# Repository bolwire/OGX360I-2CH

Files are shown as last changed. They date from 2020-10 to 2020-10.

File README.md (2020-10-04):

This project builds on the original OGX360 by Ryzee119: https://github.com/Ryzee119/ogx360/

The information provided in this repo is for informational purposes only at this time.

*****IMPORTANT******
The most recent prototype USB PCB required changes to be made, I have updated the schematic and PCB layout, and tested by modifying
the PCB I have on hand, however caution should be used until the new prototype is verified. Once I have verified the changes I will remove this
notice.

The ATMEGA32U4 chips will need to be programmed with the arduino bootloader before they are put on the PCB. One option may be to remove the chips
from an arduino and transplant them. I accomplish this currently by using a jig that I will release the files for at a later time.

More will be added to this repo as I find time over the next week.

Please respect the license files found within this project. What we do, and the joy we gain from that would not be possible without those who shared the
information with us to start with. Please respect and honor that by doing the same with any works derived from this or other projects linked to in this repo.

Also my spelling sucks, so I apologize for any type-ohs that exist.

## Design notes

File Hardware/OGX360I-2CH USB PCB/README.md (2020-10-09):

# OGX360I-2CH USB PCB.
This board was designed using [Autodesk Eagle](https://www.autodesk.com/products/eagle/overview). You can edit the `.brd` and `.sch` with this program.

## Printed Circuit Board
When fabricating your own, you can download the premade gerbers or generate your own. Suggested PCB properties are:  <br>
*2 layers, 19x42mm, 1.6mm thick, HASL, 1oz copper, no castellated holes, any colour you want!*<br>

## Bill of Materials
All the passive components listed (Resistors, capacitors etc) are listed for reference only. Any equivalents you find would be suitable. Use your best judgement. 
You should check this list against the schematic to ensure nothing is missed.  
**Digikey Quick Cart: http://www.digikey.com/short/zw017j**  

| Qty | Value/Model | Description | Marking | URL (Passive components provided as sample only) |
| --- | --- | --- | --- | --- |
| 1 | RC0805JR-0791RL | RES SMD 91 OHM 5% 1/8W 0805 | R1 | https://www.digikey.com/product-detail/en/yageo/RC0805JR-0791RL/311-91ARCT-ND/731331 |
| 1 | AU-Y1006 | CONN RCPT USB1.1 TYPEA 4P SMD RA | USB | https://www.digikey.com/product-detail/en/assmann-wsw-components/AU-Y1006/AE11182-ND/278927 |
| 1 | PCM12SMTR | SWITCH SLIDE SPDT 300MA 6V | SW1 | https://www.digikey.com/product-detail/en/c-k/PCM12SMTR/401-2016-1-ND/1640125 |
| 1 | SM06B-SRSS-TB(LF)(SN) | CONN HEADER SMD R/A 6POS 1MM | CONN / J1 | https://www.digikey.com/product-detail/en/jst-sales-america-inc/SM06B-SRSS-TB-LF-SN/455-1806-1-ND/926877 |
| 1 | A06SR06SR30K254A | JUMPER 06SR-3S - 06SR-3S 10" | CABLE | https://www.digikey.com/product-detail/en/jst-sales-america-inc/A06SR06SR30K254A/455-3647-ND/9922197 |
| 1 | 150080GS75000 | LED GREEN CLEAR 0805 SMD | LED | https://www.digikey.com/product-detail/en/w-rth-elektronik/150080GS75000/732-4983-1-ND/4489913 |

## Assembled Photo (coming soon)
Top Side Photo
Bottom Side Photo
By KingLuxor

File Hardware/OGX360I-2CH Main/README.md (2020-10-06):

# OGX360I-2CH Main PCB.
This board was designed using [Autodesk Eagle](https://www.autodesk.com/products/eagle/overview). You can edit the `.brd` and `.sch` with this program.

## Printed Circuit Board
When fabricating your own, you can download the premade gerbers or generate your own. Suggested PCB properties are:  <br>
*2 layers, 35x71mm, 1.6mm thick, HASL, 1oz copper, no castellated holes, any colour you want!*<br>

## Bill of Materials
All the passive components listed (Resistors, capacitors etc) are listed for reference only. Any equivalents you find would be suitable. Use your best judgement. 
You should check this list against the schematic to ensure nothing is missed.  
**Digikey Quick Cart: http://www.digikey.com/short/zwrw47**  

| Qty | Value/Model | Description | Marking | URL (Passive components provided as sample only) |
| --- | --- | --- | --- | --- |
| 2 | B12B-PHDSS(LF)(SN) | CONN HEADER VERT 12POS 2MM | J4,J5 | https://www.digikey.com/product-detail/en/jst-sales-america-inc/B12B-PHDSS-LF-SN/455-1763-ND/926669 |
| 1 | ‎B6B-PH-K-S(LF)(SN) | CONN HEADER VERT 6POS 2MM | J6 | https://www.digikey.com/product-detail/en/jst-sales-america-inc/B6B-PH-K-S-LF-SN/455-1708-ND/926615 |
| 1 | MIC5219-3.3YM5-TR | IC REG LINEAR 3.3V 500MA SOT23-5‎ | U3 | https://www.digikey.com/product-detail/en/microchip-technology/MIC5219-3.3YM5-TR/576-1281-1-ND/771902 |
| 9 | 08056D104KAT2A | CAP CER 0.1UF 6.3V X5R 0805 | C1,4-5,7-8,10-11,15-16 | https://www.digikey.com/product-detail/en/avx-corporation/08056D104KAT2A/478-08056D104KAT2ACT-ND/11569296 |
| 2 | CC0805JRNPO9BN180 | CAP CER 18PF 50V C0G/NPO 0805 | C2-3 | https://www.digikey.com/product-detail/en/yageo/CC0805JRNPO9BN180/311-1102-1-ND/303012 |
| 1 | EDK106M035A9BAA | CAP ALUM 10UF 20% 35V SMD | C6 | https://www.digikey.com/product-detail/en/kemet/EDK106M035A9BAA/399-14794-1-ND/7319832 |
| 2 | C0805C105Z4VACTU | CAP CER 1UF 16V Y5V 0805 | C9, C14 | https://www.digikey.com/product-detail/en/kemet/C0805C105Z4VACTU/399-8011-1-ND/3471734 |
| 4 | C0805C220J5GACTU | CAP CER 22PF 50V C0G/NP0 0805 | C12-13,17-18 | https://www.digikey.com/product-detail/en/kemet/C0805C220J5GACTU/399-1113-1-ND/411388 |
| 2 | 10118192-0001LF | CONN RCPT USB2.0 MICRO B SMD R/A | J2-3 | https://www.digikey.com/product-detail/en/amphenol-icc-fci/10118192-0001LF/609-4613-1-ND/2785378 |
| 2 | RC0805FR-0733RL | RES SMD 33 OHM 1% 1/8W 0805 | R1-2 | https://www.digikey.com/product-detail/en/yageo/RC0805FR-0733RL/311-33.0CRCT-ND/730809 |
| 2 | RC0805FR-072KL | RES SMD 2K OHM 1% 1/8W 0805 | R3-4 | https://www.digikey.com/product-detail/en/yageo/RC0805FR-072KL/311-2.00KCRCT-ND/730611 |
| 1 | RC0805JR-071KL | RES SMD 1K OHM 5% 1/8W 0805 | R5 | https://www.digikey.com/product-detail/en/yageo/RC0805JR-071KL/311-1.0KARCT-ND/731165 |
| 4 | RC0805JR-0722RL | RES SMD 22 OHM 5% 1/8W 0805 | R6-7,9-10 | https://www.digikey.com/product-detail/en/yageo/RC0805JR-0722RL/311-22ARCT-ND/731232 |
| 2 | RC0805FR-0710KL | RES SMD 10K OHM 1% 1/8W 0805 | R8,R11 | https://www.digikey.com/product-detail/en/yageo/RC0805FR-0710KL/311-10.0KCRCT-ND/730482 |
| 1 | TL3305AF160QG | SWITCH TACTILE SPST-NO 50MA 12V | RESET | https://www.digikey.com/product-detail/en/e-switch/TL3305AF160QG/EG5350CT-ND/5816195 |
| 1 | MAX3421EEHJ+T | IC USB PERIPH/HOST CNTRL 32TQFP | U1 | https://www.digikey.com/product-detail/en/maxim-integrated/MAX3421EEHJ-T/MAX3421EEHJ-TCT-ND/4895460 |
| 1 | CD74HC4050M96 | IC BUFFER NON-INVERT 6V 16SOIC | U2 | https://www.digikey.com/product-detail/en/texas-instruments/CD74HC4050M96/296-14529-1-ND/555596 |
| 2 | ATMEGA32U4-AUR | IC MCU 8BIT 32KB FLASH 44TQFP | U4-5 | https://www.digikey.com/product-detail/en/microchip-technology/ATMEGA32U4-AUR/ATMEGA32U4-AURCT-ND/3440960 |
| 2 | TSX-3225 16.0000MF09Z-AC0 | CRYSTAL 16.0000MHZ 9PF SMD | X2-3 | https://www.digikey.com/product-detail/en/epson/TSX-3225-16.0000MF09Z-AC0/SER4069CT-ND/5413938 |
| 1 | FA-238V 12.0000MB-W3 | CRYSTAL 12.0000MHZ 12PF SMD | X1 | https://www.digikey.com/product-detail/en/epson/FA-238V-12.0000MB-W3/SER3683CT-ND/2403456 |
| 2 | PHDR-12VS | CONN HOUSING PHD 12POS 2MM DUAL | --- | https://www.digikey.com/product-detail/en/jst-sales-america-inc/PHDR-12VS/455-1204-ND/608645 |
| 10 | APAPA22K152 | JUMPER SPHD-001T-P0.5 X2 6" | --- | https://www.digikey.com/product-detail/en/jst-sales-america-inc/APAPA22K152/455-3085-ND/6009461 |
| 1 | 0ZCJ0050FF2G | PTC RESET FUSE 8V 500MA 1206 | F1 | https://www.digikey.com/product-detail/en/bel-fuse-inc/0ZCJ0050FF2G/507-1802-1-ND/4156236 |
| 2 | TMUX1237DCKR | PRECISION ANALOG MULTIPLEXER | U6-7 | https://www.digikey.com/product-detail/en/texas-instruments/TMUX1237DCKR/296-TMUX1237DCKRCT-ND/12165699 |
| 1 | SM06B-SRSS-TB(LF)(SN) | CONN HEADER SMD R/A 6POS 1MM | J7 | https://www.digikey.com/product-detail/en/jst-sales-america-inc/SM06B-SRSS-TB-LF-SN/455-1806-1-ND/926877 |

## Assembled Photo
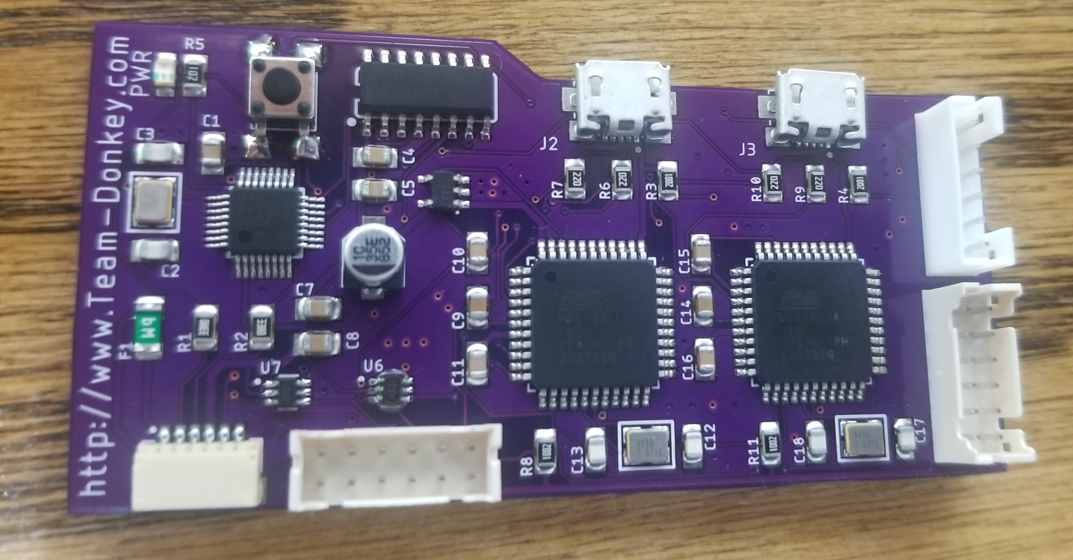
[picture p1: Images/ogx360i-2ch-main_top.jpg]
Top Side Photo

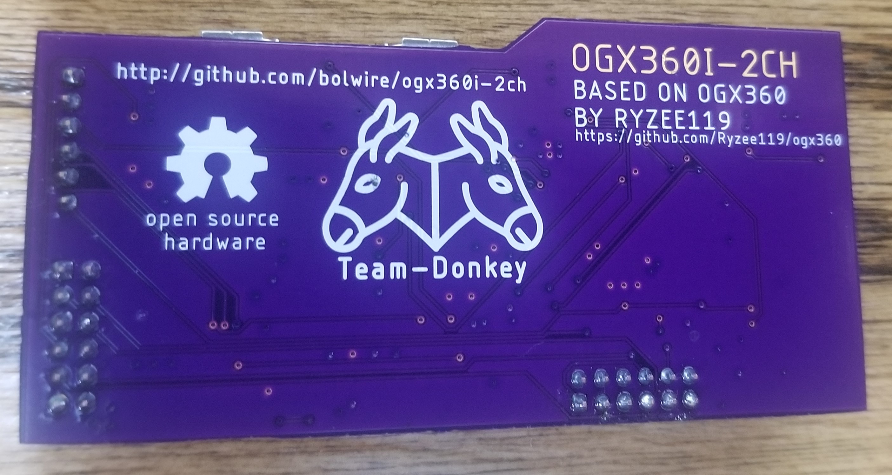
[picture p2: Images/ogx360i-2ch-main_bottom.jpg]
Bottom Side Photo

By KingLuxor

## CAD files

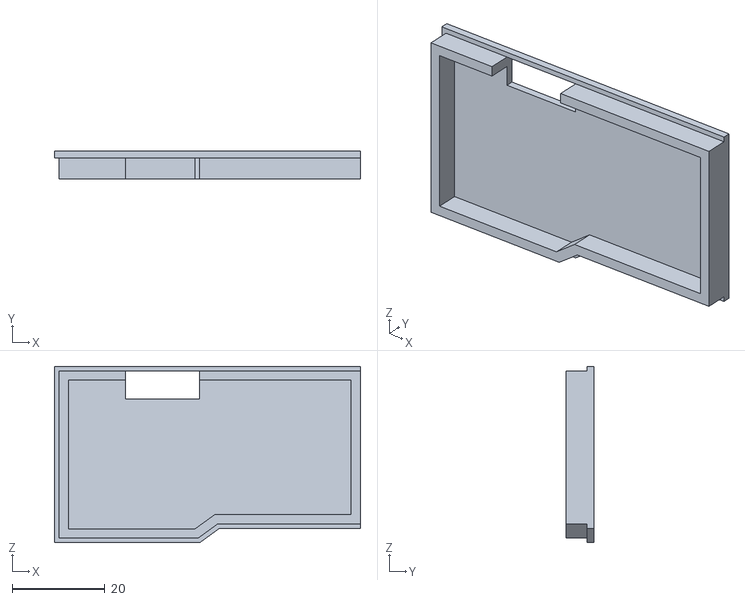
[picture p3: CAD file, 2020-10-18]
Case/OGX360I-top.stl
65.9 x 6.00 x 38.0

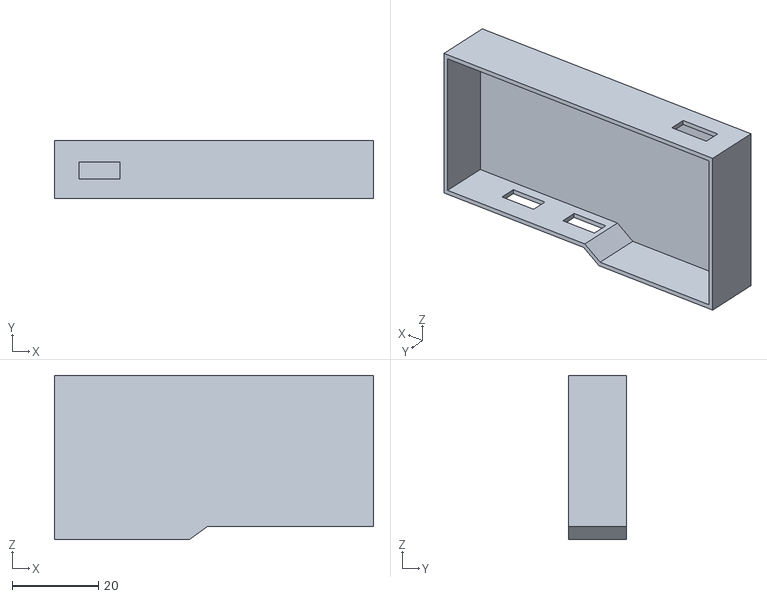
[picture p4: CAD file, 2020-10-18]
Case/OGX36I-bottom.stl
73.9 x 13.5 x 38.0

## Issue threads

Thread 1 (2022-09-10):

Details on Jig to burn bootloader

Robert-Such, 2022-09-10:
Would it be possible to get some of those details for the jig you are using to burn the bootloaders?  I tried to put a basic circuit together on a breadboard with a test socket(clamshell adapter) but I haven't been able to get anything working so far.  It's possible that I wired something wrong and cooked the 32u4.  Any help would be much appreciated.

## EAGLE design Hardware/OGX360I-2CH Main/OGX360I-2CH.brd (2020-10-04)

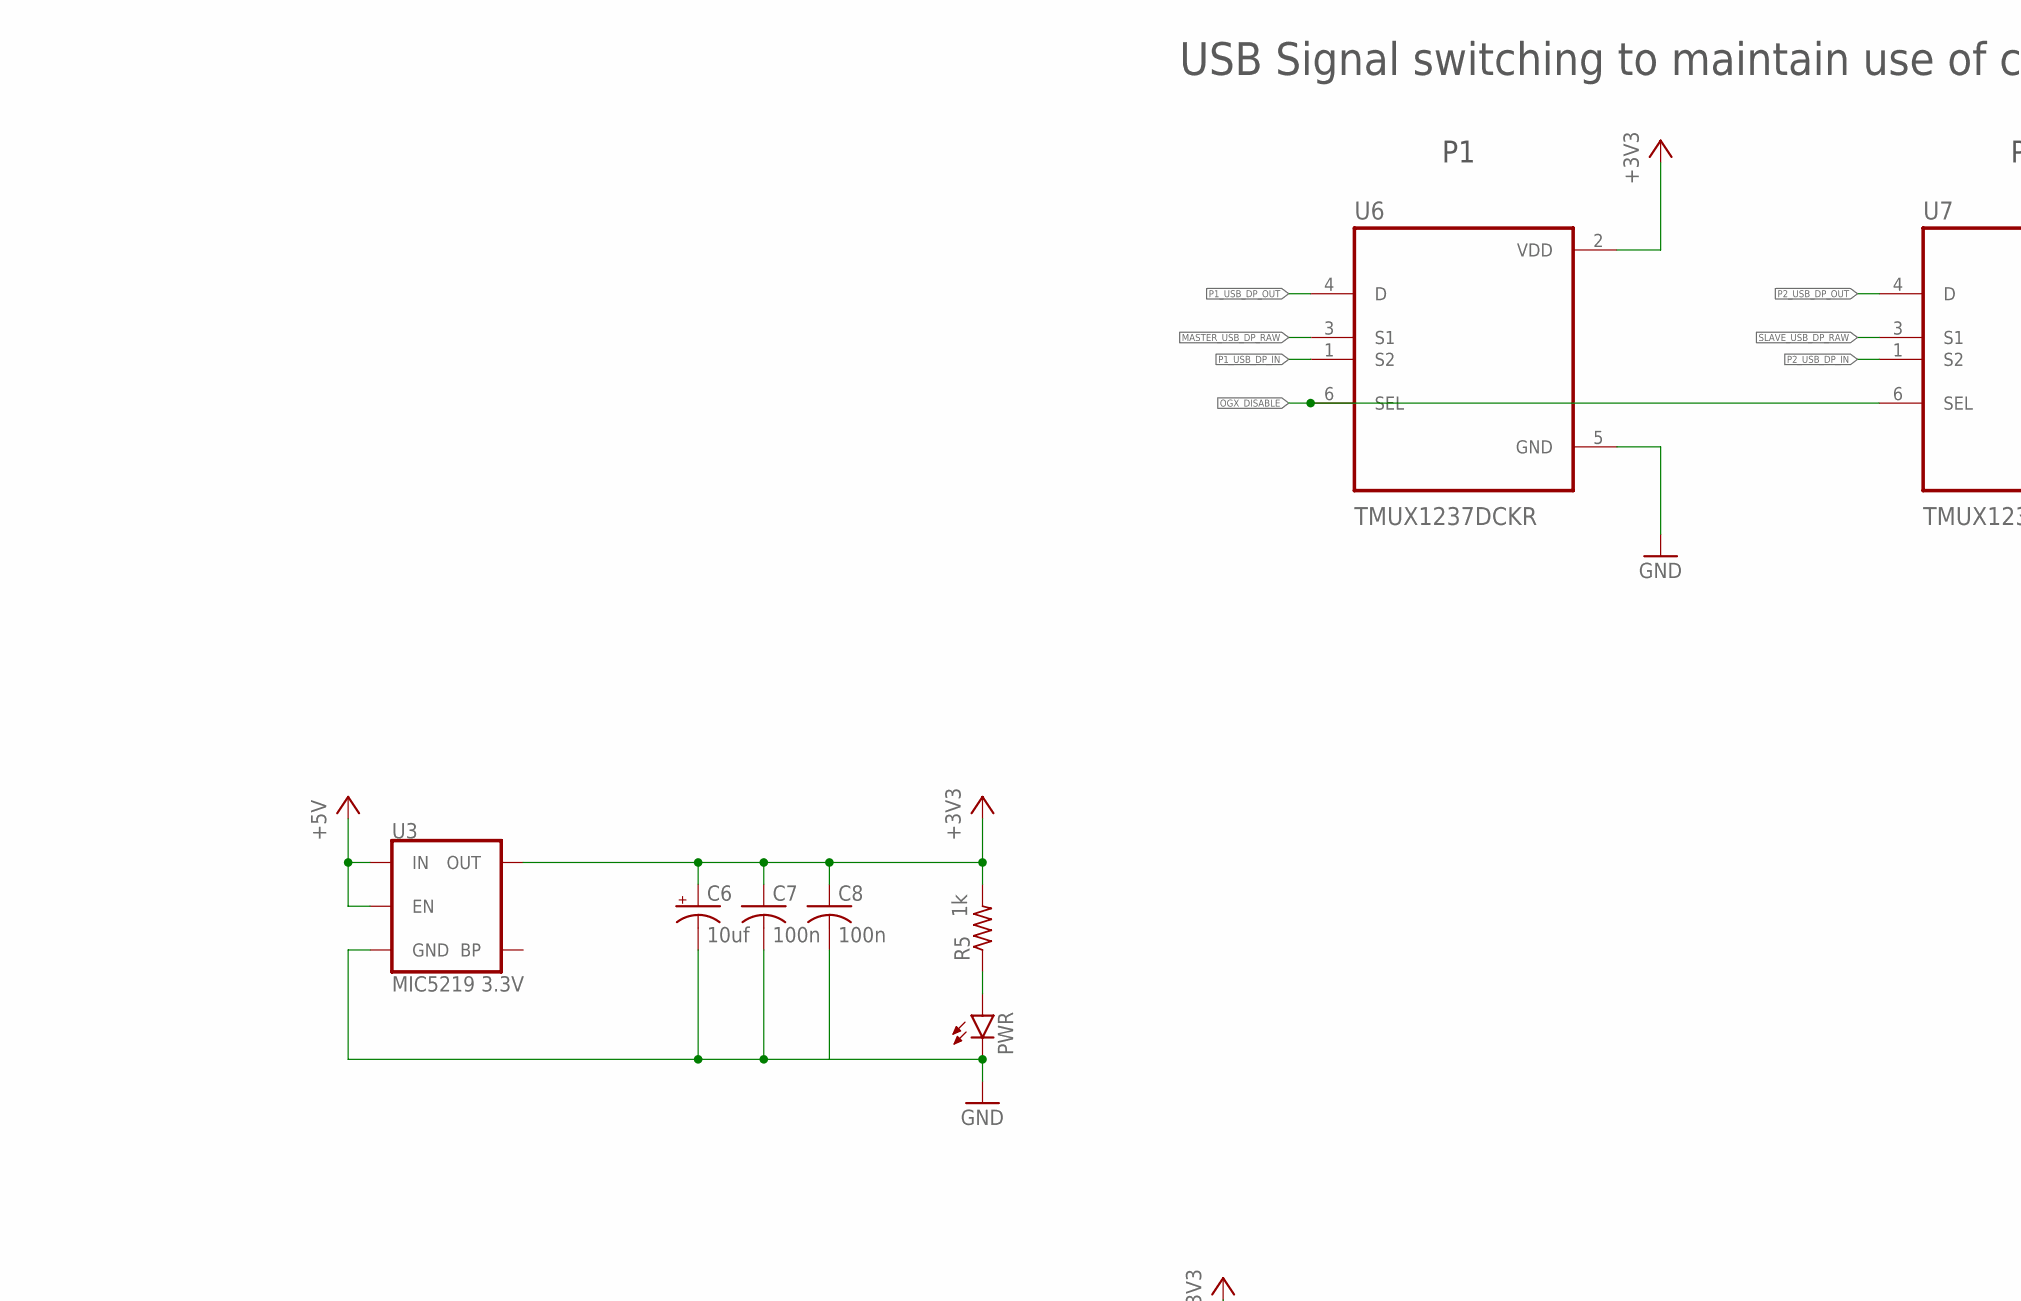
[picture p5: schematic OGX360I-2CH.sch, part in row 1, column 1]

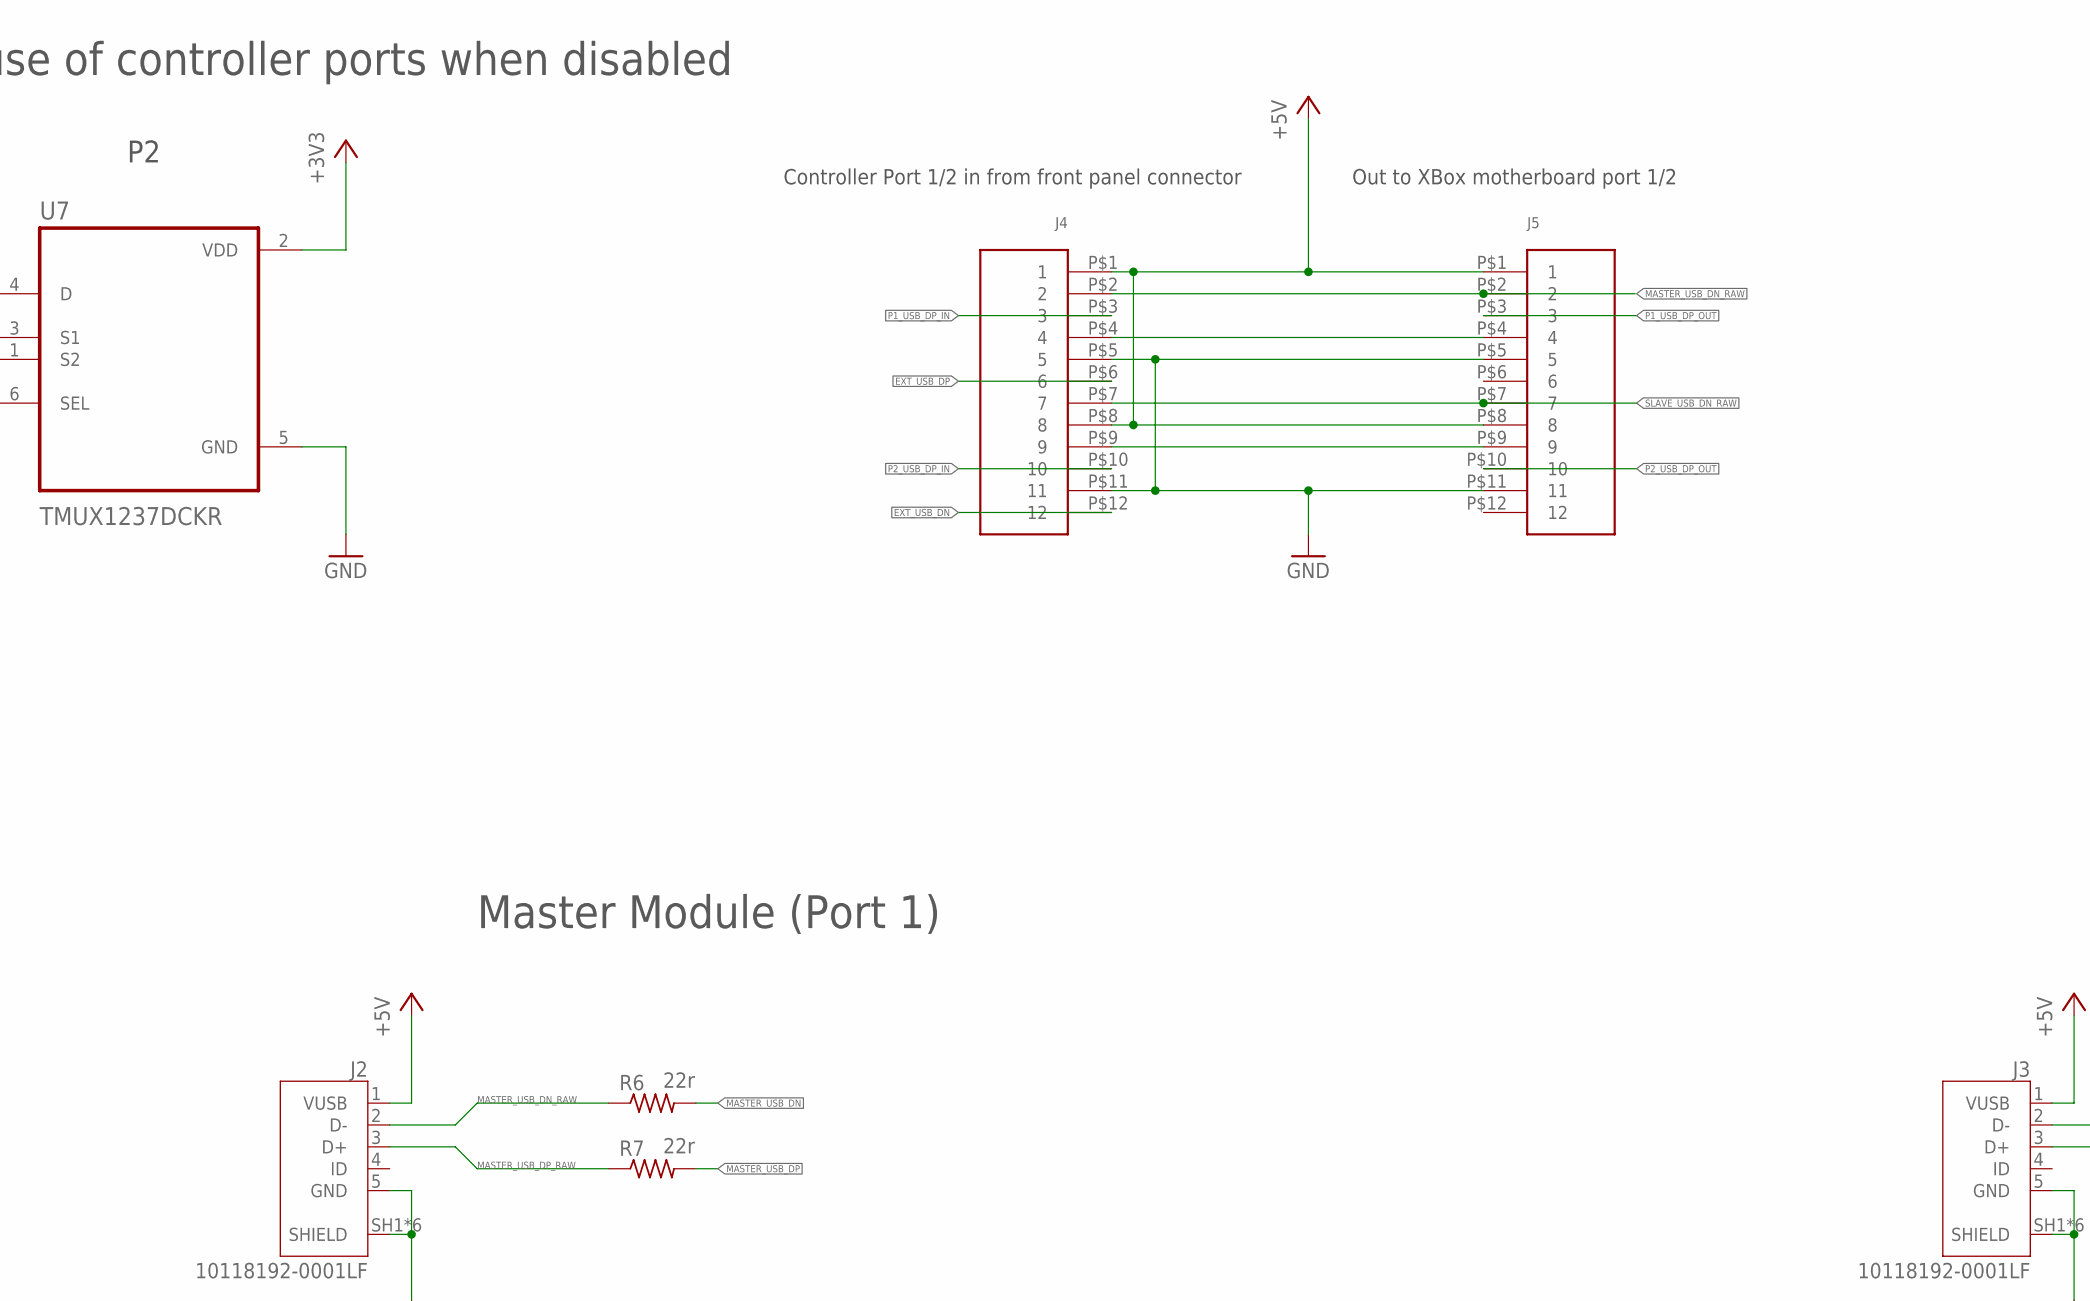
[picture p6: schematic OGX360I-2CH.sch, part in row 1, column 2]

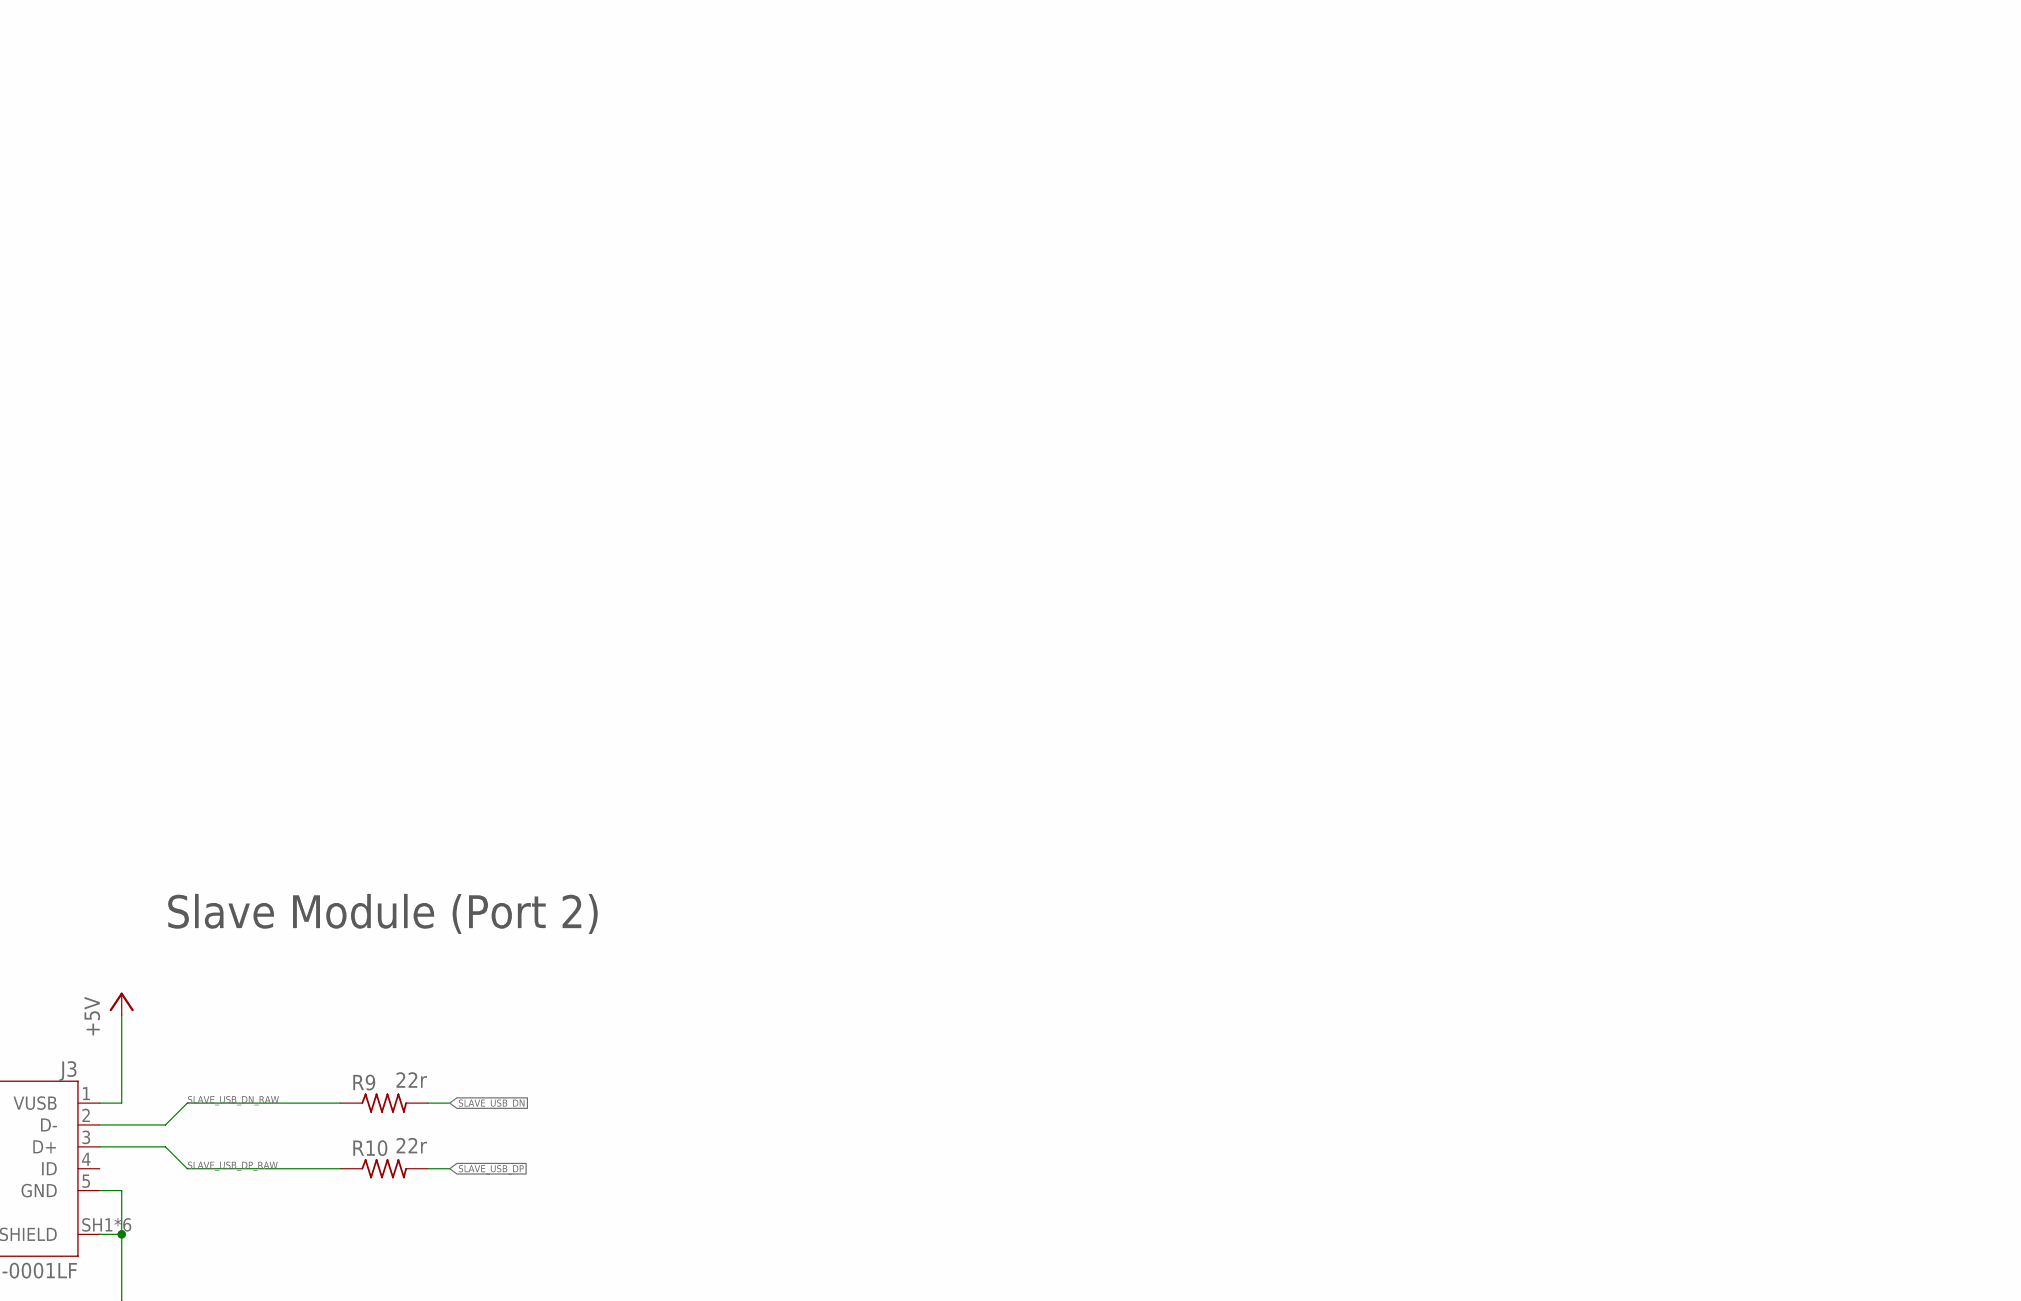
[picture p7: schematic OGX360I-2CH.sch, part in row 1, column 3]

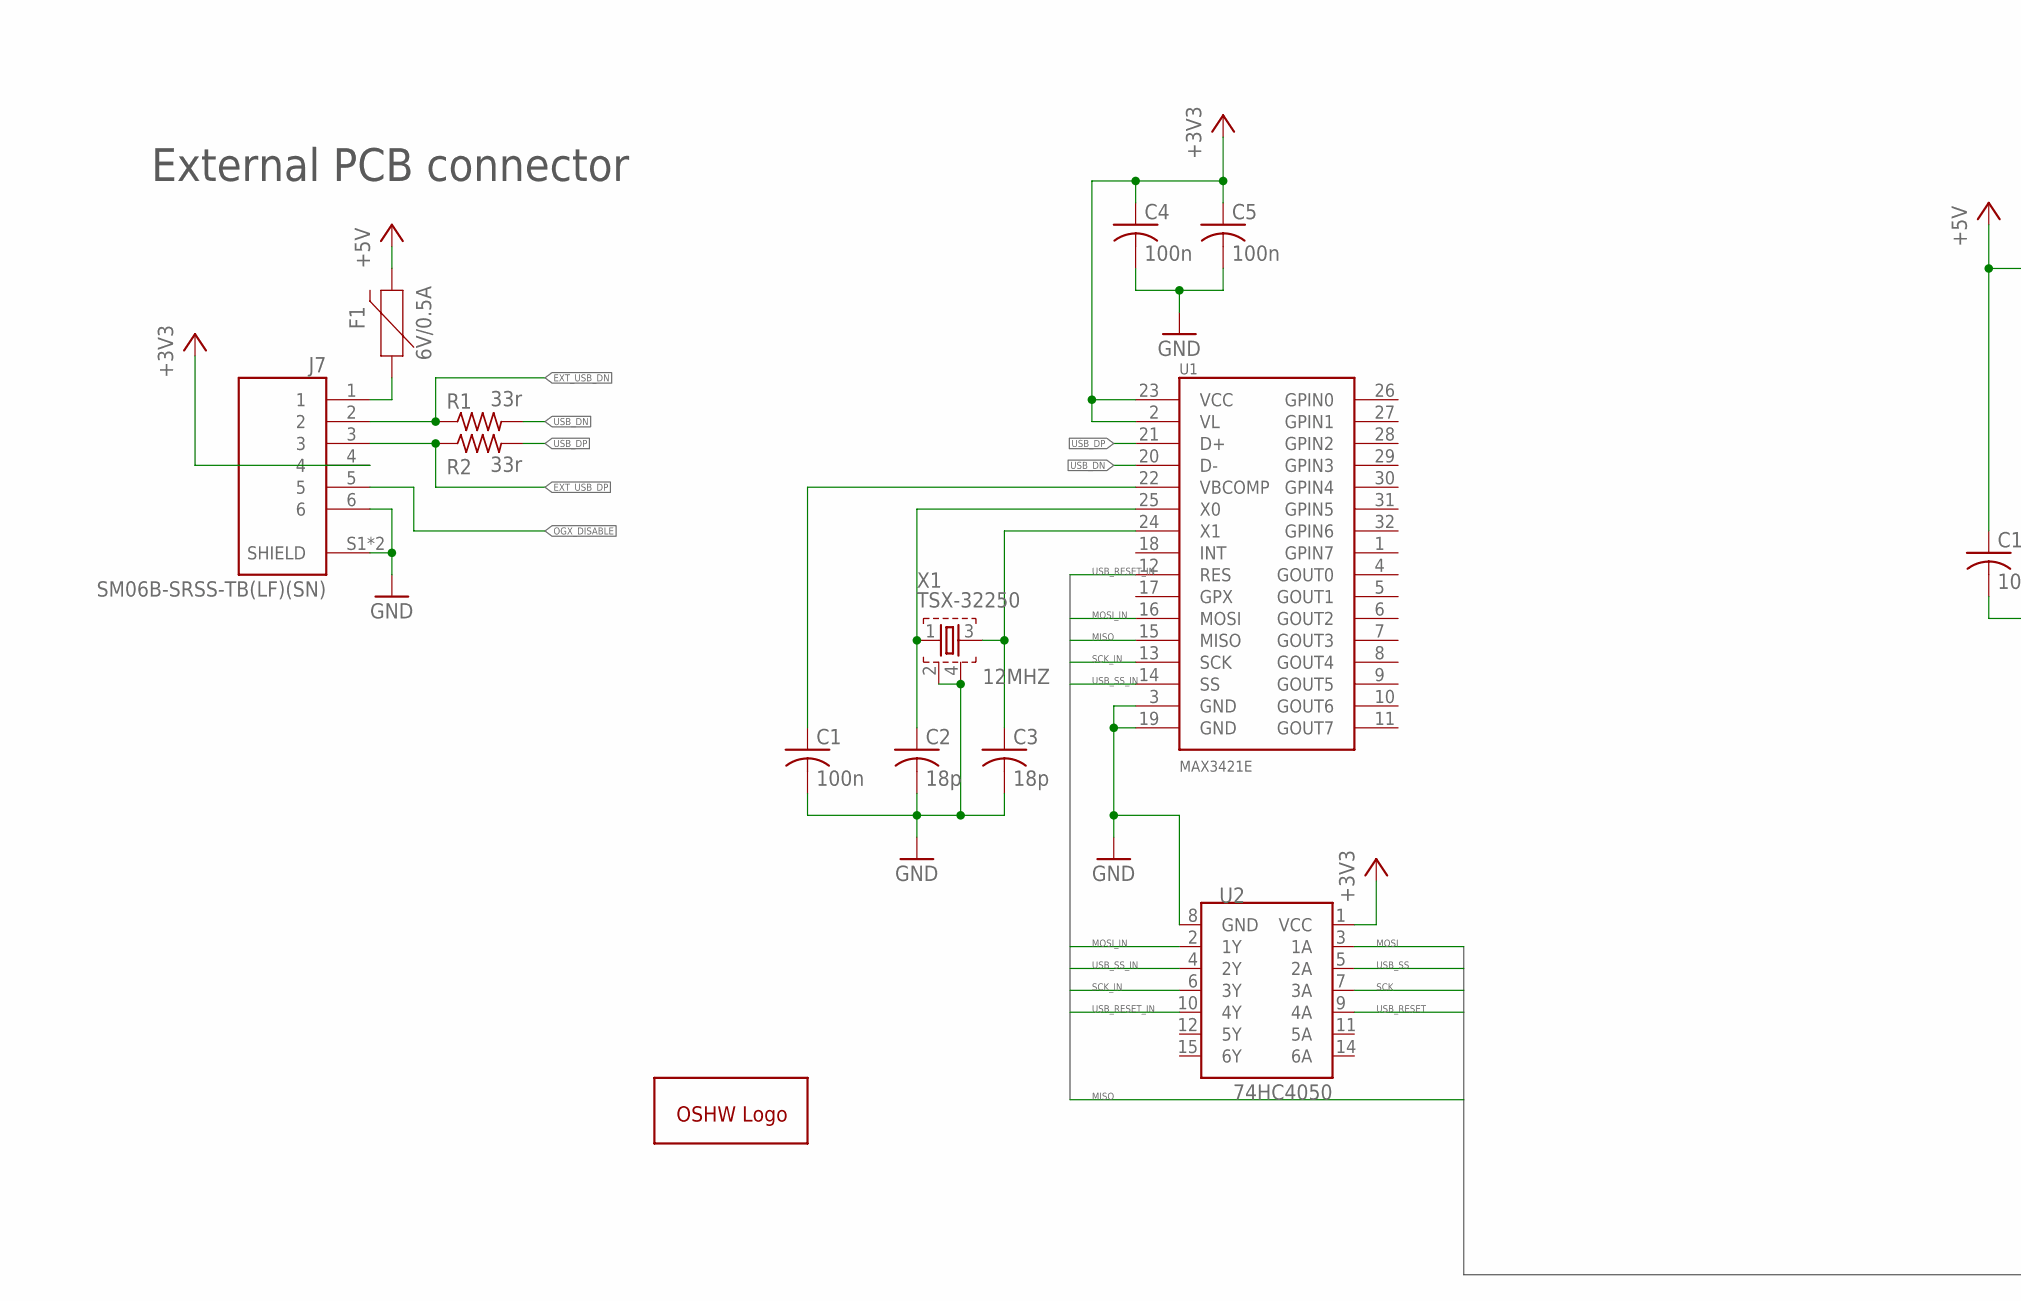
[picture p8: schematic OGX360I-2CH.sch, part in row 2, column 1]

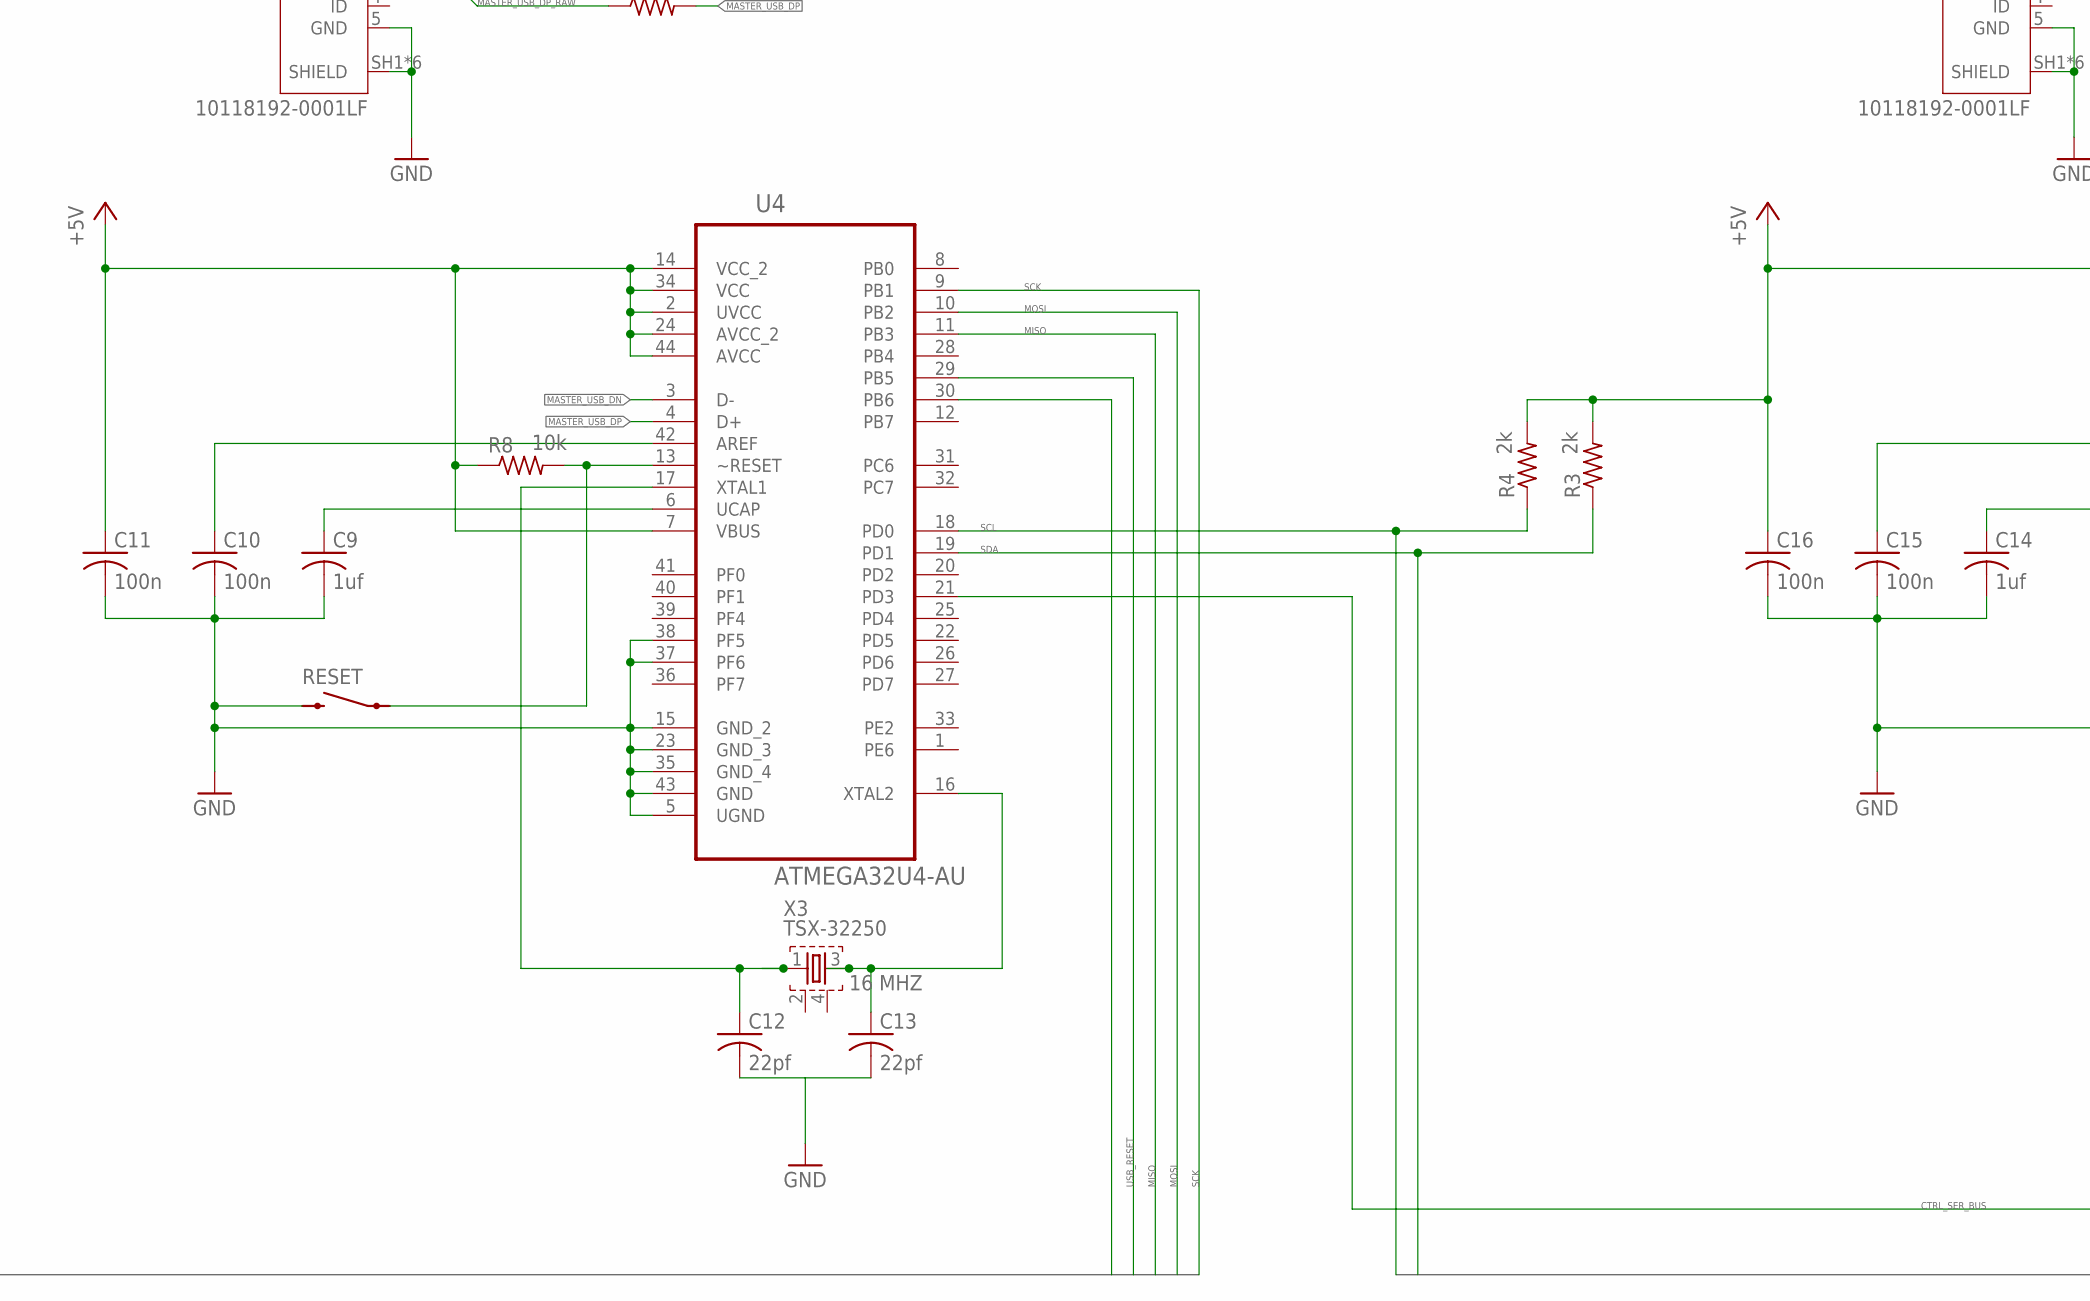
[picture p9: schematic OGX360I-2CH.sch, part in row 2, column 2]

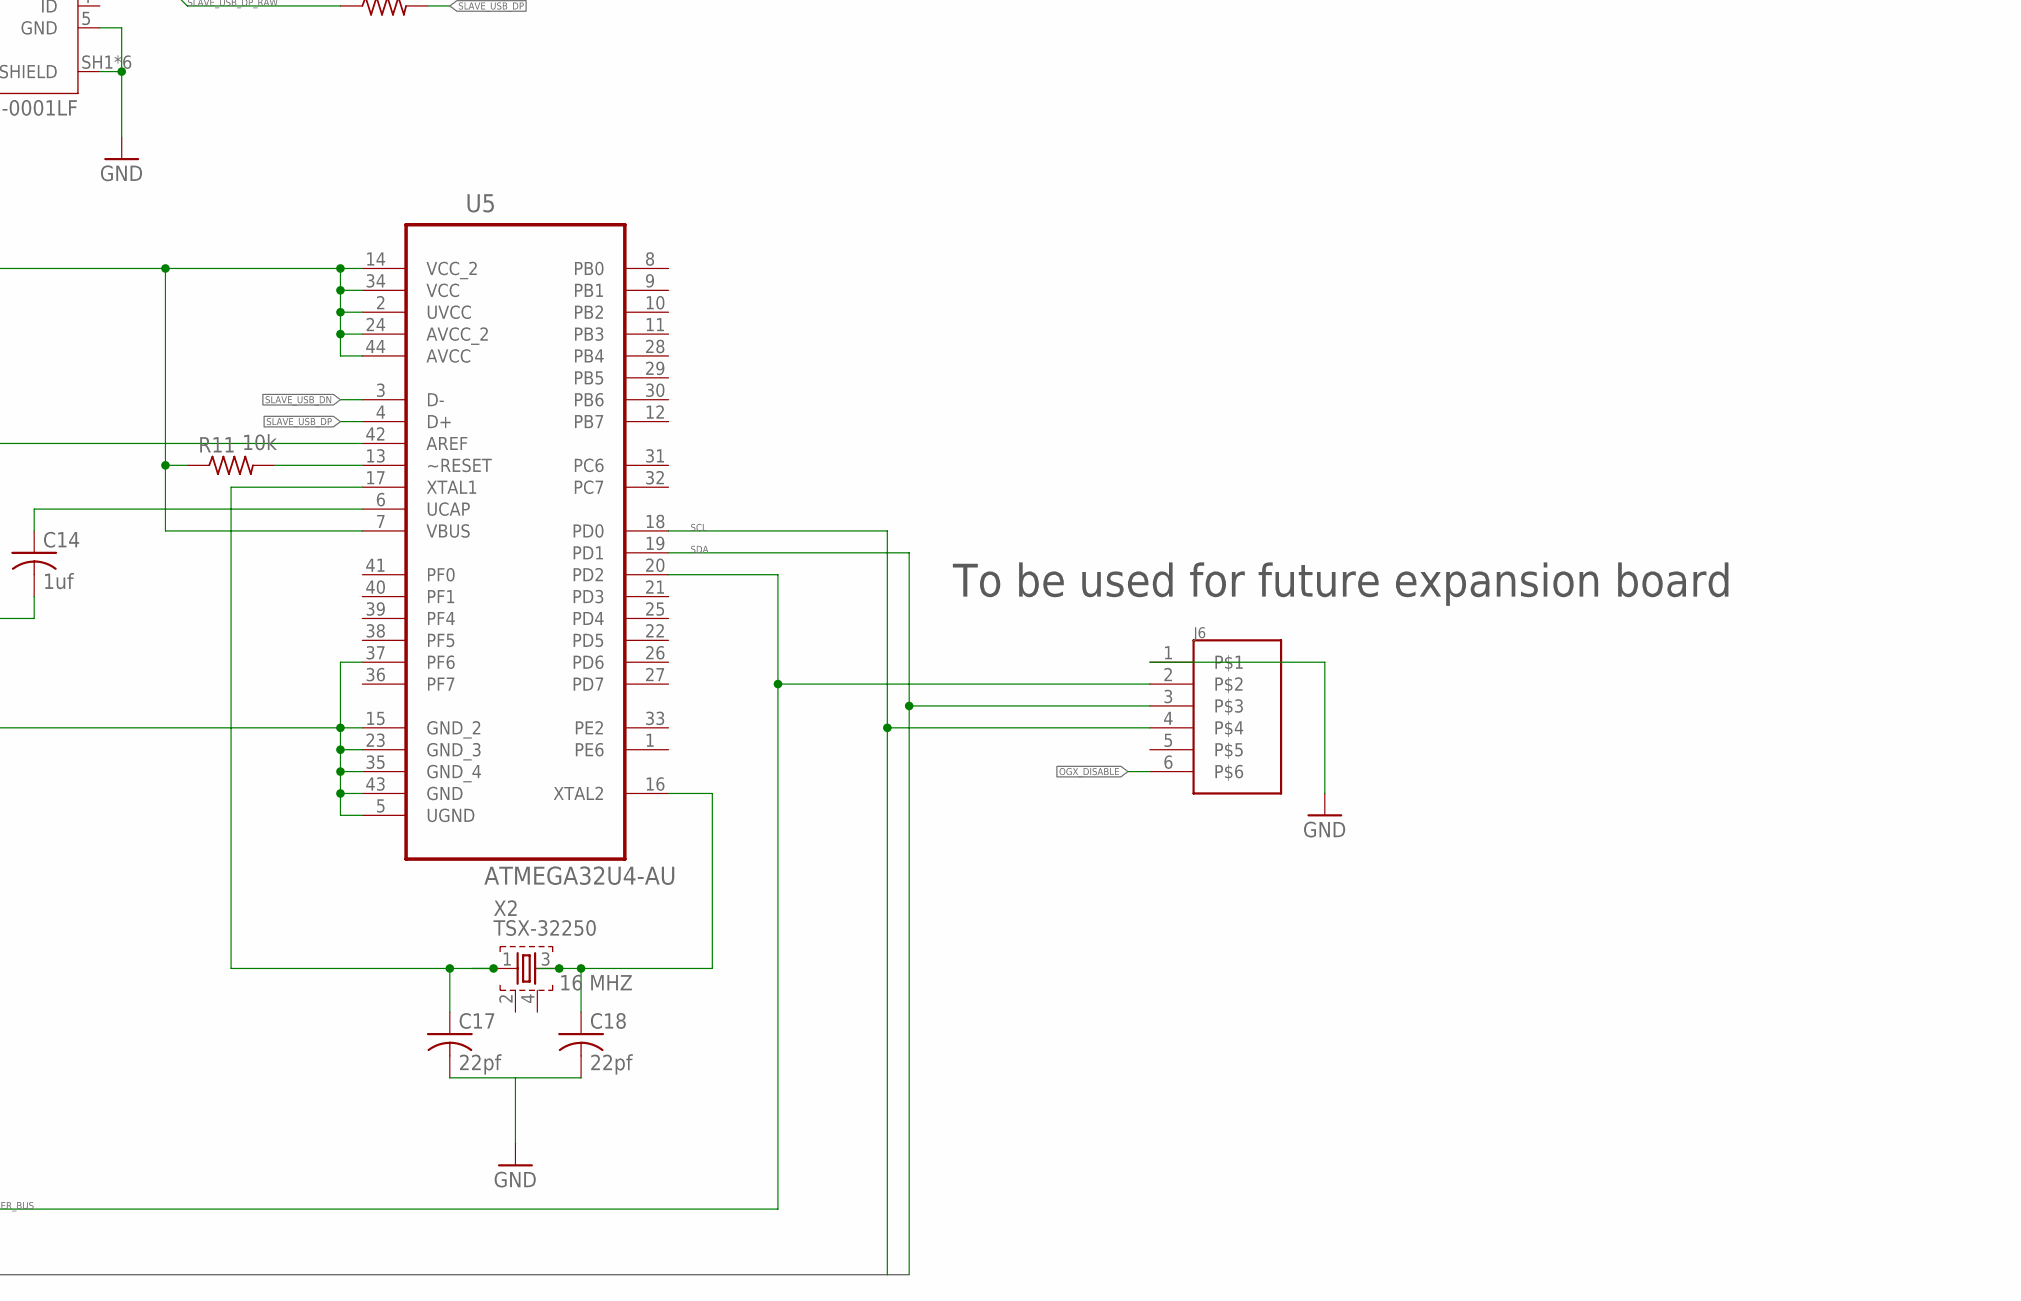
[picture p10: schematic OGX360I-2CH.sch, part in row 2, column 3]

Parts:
C1, C4, C5, C7, C8, C10, C11, C15, C16: 100n; C0805
C2, C3: 18p; C0805
C6: 10uf; 153CLV-0405
C9, C14: 1uf; C0805
C12, C13, C17, C18: 22pf; C0805
F1: 6V/0.5A; 1206
GOLD_ORB_SM1: OSHWLOGOLOGO8MM; OSHW_8MM
J2, J3: 10118192-0001LF; AMPHENOL_10118192-0001LF
J4, J5: B12B-PHDSS
J6: B6B-PH-K-S; B6B-PH-K
J7: SM06B-SRSS-TB(LF)(SN); JST_SM06B-SRSS-TB(LF)(SN)
PWR: LEDCHIP-LED0805; CHIP-LED0805
R1, R2: 33r; M0805
R3, R4: 2k; M0805
R5: 1k; M0805
R6, R7, R9, R10: 22r; M0805
R8, R11: 10k; M0805
RESET: TL3305AF160QG
U1: MAX3421E; TQFP32-5MM
U2: 74HC4050; SO16
U3: MIC5219 3.3V; SOT23-5
U4, U5: ATMEGA32U4-AU; QFP80P1200X1200X120-44N
U6, U7: TMUX1237DCKR; SOT65P210X110-6N
X1, X2, X3: TSX-32250; TSX-3225

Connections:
+3V3: C4.1, C5.1, C6.+, C7.1, C8.1, J7.4, R5.2, U1.2 (VL), U1.23 (VCC), U2.1 (VCC), U3.5 (OUT), U6.2 (VDD), U7.2 (VDD)
+5V: C11.1, C16.1, F1.2, J2.1 (VUSB), J3.1 (VUSB), J4.P$1 (1), J4.P$8 (8), J5.P$1 (1), J5.P$8 (8), R3.2, R4.2, R8.1, R11.1, U3.1 (IN), U3.3 (EN), U4.2 (UVCC), U4.7 (VBUS), U4.14 (VCC_2), U4.24 (AVCC_2), U4.34 (VCC), U4.44 (AVCC), U5.2 (UVCC), U5.7 (VBUS), U5.14 (VCC_2), U5.24 (AVCC_2), U5.34 (VCC), U5.44 (AVCC)
CTRL_SER_BUS: J6.2, U4.21 (PD3), U5.20 (PD2)
EXT_USB_DN: J4.P$12 (12), J7.2, R1.1
EXT_USB_DP: J4.P$6 (6), J7.3, R2.1
GND: C1.2, C2.2, C3.2, C4.2, C5.2, C6.-, C7.2, C8.2, C9.2, C10.2, C11.2, C12.2, C13.2, C14.2, C15.2, C16.2, C17.2, C18.2, J2.5 (GND), J2.SH1 (SHIELD), J2.SH2 (SHIELD), J2.SH3 (SHIELD), J2.SH4 (SHIELD), J2.SH5 (SHIELD), J2.SH6 (SHIELD), J3.5 (GND), J3.SH1 (SHIELD), J3.SH2 (SHIELD), J3.SH3 (SHIELD), J3.SH4 (SHIELD), J3.SH5 (SHIELD), J3.SH6 (SHIELD), J4.P$5 (5), J4.P$11 (11), J5.P$5 (5), J5.P$11 (11), J6.1, J7.6, J7.S1 (SHIELD), J7.S2 (SHIELD), PWR.C, RESET.P$1, RESET.P$2, U1.3 (GND), U1.19 (GND), U2.8 (GND), U3.2 (GND), U4.5 (UGND), U4.15 (GND_2), U4.23 (GND_3), U4.35 (GND_4), U4.37 (PF6), U4.38 (PF5), U4.43 (GND), U5.5 (UGND), U5.15 (GND_2), U5.23 (GND_3), U5.35 (GND_4), U5.37 (PF6), U5.43 (GND), U6.5 (GND), U7.5 (GND), X1.2, X1.4
MASTER_USB_DN: R6.2, U4.3 (D-)
MASTER_USB_DN_RAW: J2.2 (D-), J4.P$2 (2), J5.P$2 (2), R6.1
MASTER_USB_DP: R7.2, U4.4 (D+)
MASTER_USB_DP_RAW: J2.3 (D+), R7.1, U6.3 (S1)
MISO: U1.15 (MISO), U4.11 (PB3)
MOSI: U2.3 (1A), U4.10 (PB2)
MOSI_IN: U1.16 (MOSI), U2.2 (1Y)
unnamed: C13.1, U4.16 (XTAL2), X3.3
unnamed: C3.1, U1.24 (X1), X1.3
unnamed: F1.1, J7.1
unnamed: PWR.A, R5.1
unnamed: C2.1, U1.25 (X0), X1.1
unnamed: C1.1, U1.22 (VBCOMP)
unnamed: C9.1, U4.6 (UCAP)
unnamed: C10.1, U4.42 (AREF)
unnamed: C12.1, U4.17 (XTAL1), X3.1
unnamed: C14.1, U5.6 (UCAP)
unnamed: C15.1, U5.42 (AREF)
unnamed: C18.1, U5.16 (XTAL2), X2.3
unnamed: C17.1, U5.17 (XTAL1), X2.1
unnamed: J4.P$4 (4), J5.P$4 (4)
unnamed: J4.P$9 (9), J5.P$9 (9)
OGX_DISABLE: J6.6, J7.5, U6.6 (SEL), U7.6 (SEL)
P1_USB_DP_IN: J4.P$3 (3), U6.1 (S2)
P1_USB_DP_OUT: J5.P$3 (3), U6.4 (D)
P2_USB_DP_IN: J4.P$10 (10), U7.1 (S2)
P2_USB_DP_OUT: J5.P$10 (10), U7.4 (D)
RESET: R8.2, R11.2, RESET.P$3 (2), RESET.P$4 (2), U4.13 (~RESET), U5.13 (~RESET)
SCK: U2.7 (3A), U4.9 (PB1)
SCK_IN: U1.13 (SCK), U2.6 (3Y)
SCL: J6.4, R4.1, U4.18 (PD0), U5.18 (PD0)
SDA: J6.3, R3.1, U4.19 (PD1), U5.19 (PD1)
SLAVE_USB_DN: R9.2, U5.3 (D-)
SLAVE_USB_DN_RAW: J3.2 (D-), J4.P$7 (7), J5.P$7 (7), R9.1
SLAVE_USB_DP: R10.2, U5.4 (D+)
SLAVE_USB_DP_RAW: J3.3 (D+), R10.1, U7.3 (S1)
USB_DN: R1.2, U1.20 (D-)
USB_DP: R2.2, U1.21 (D+)
USB_RESET: U2.9 (4A), U4.29 (PB5)
USB_RESET_IN: U1.12 (RES), U2.10 (4Y)
USB_SS: U2.5 (2A), U4.30 (PB6)
USB_SS_IN: U1.14 (SS), U2.4 (2Y)

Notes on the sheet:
Controller Port 1/2 in from front panel connector
Out to XBox motherboard port 1/2
12MHZ
16 MHZ
USB Signal switching to maintain use of controller ports when disabled
External PCB connector
Master Module (Port 1)
Slave Module (Port 2)
To be used for future expansion board

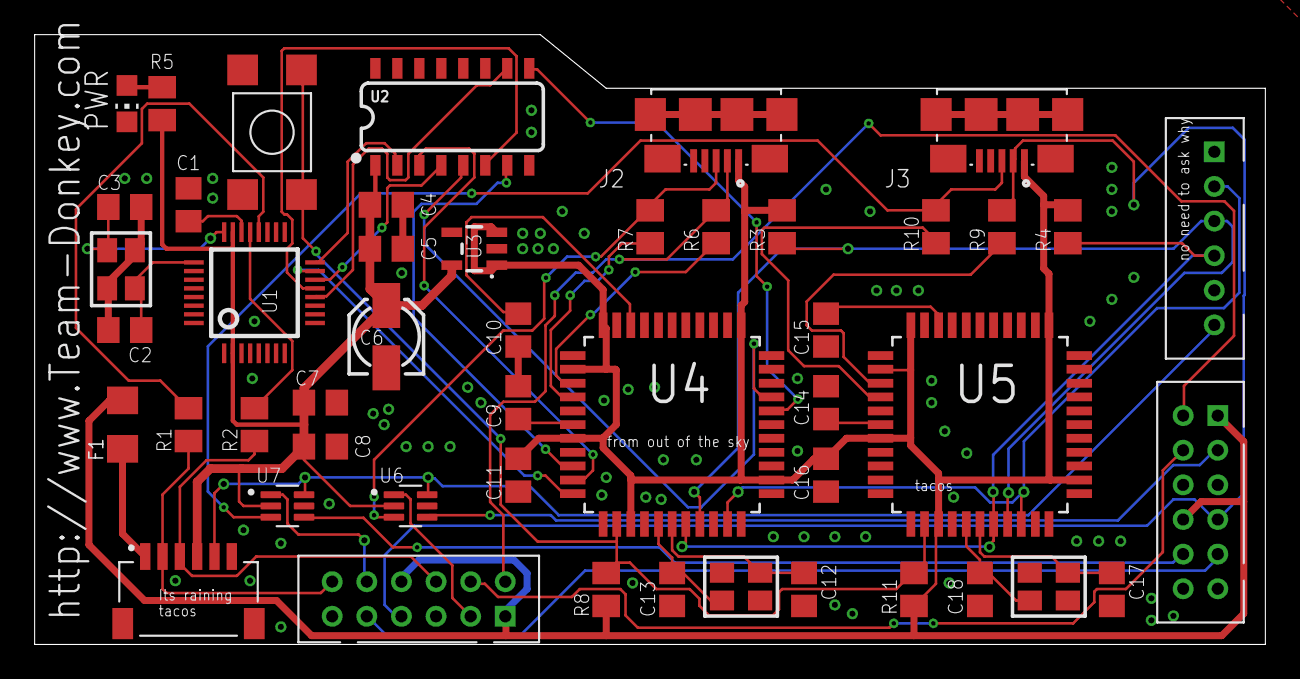
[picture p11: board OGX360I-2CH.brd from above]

Board: 2 copper layers, 71.1 x 35.2 mm, 49 parts (1 on the bottom side), 48 nets.

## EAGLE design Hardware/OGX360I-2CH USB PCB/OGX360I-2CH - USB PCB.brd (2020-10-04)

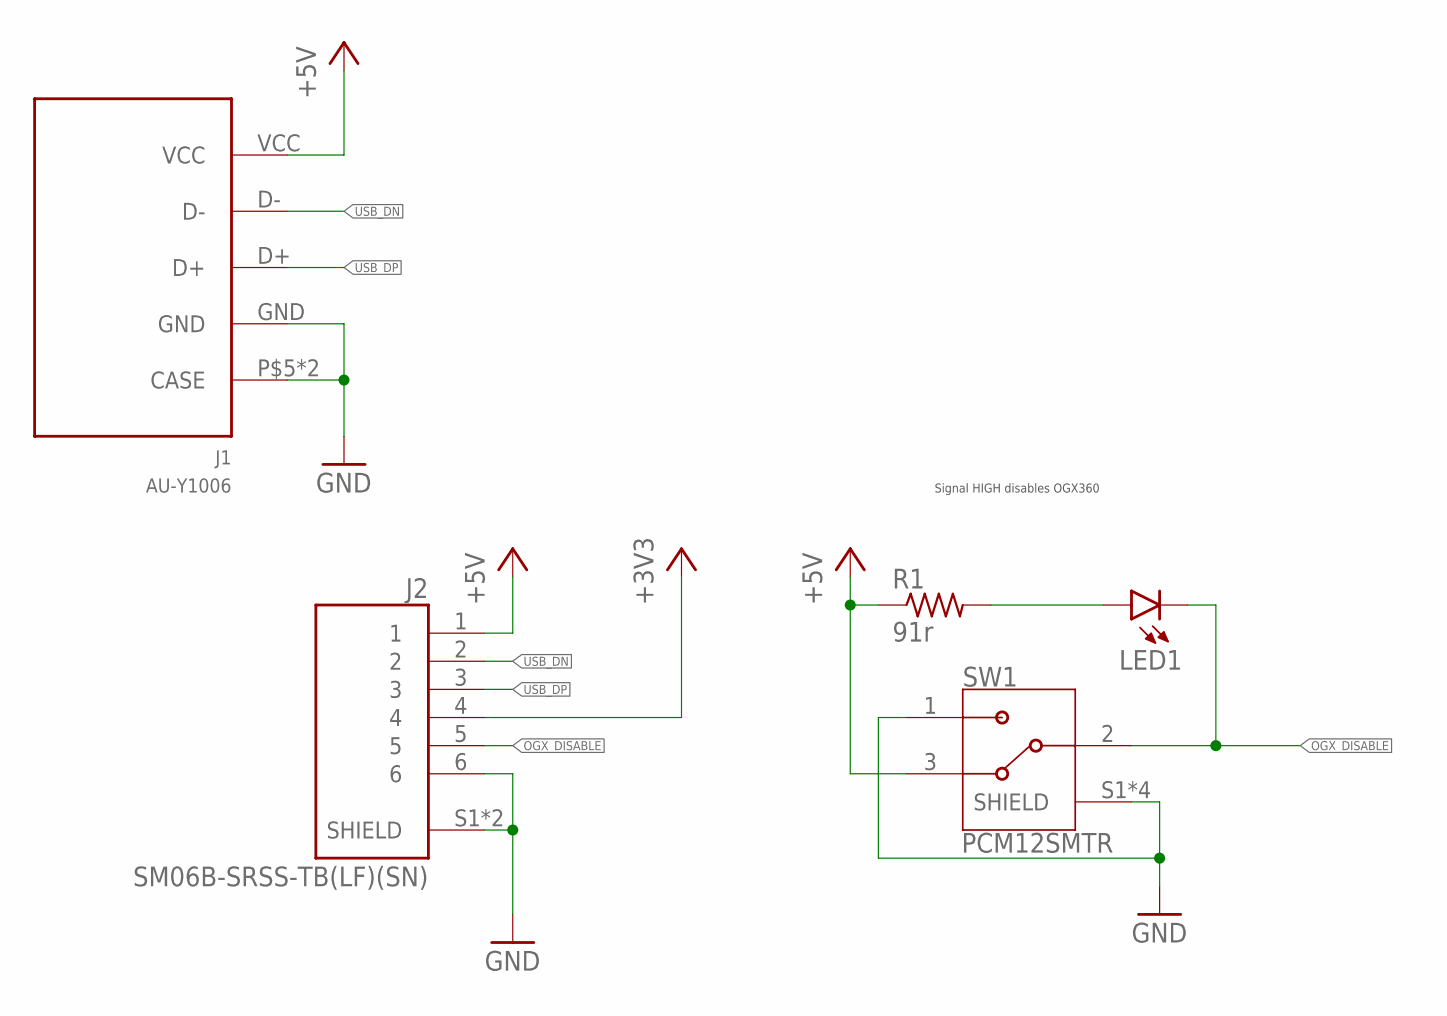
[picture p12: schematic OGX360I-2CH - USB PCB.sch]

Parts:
J1: AU-Y1006; USBA_SMD
J2: SM06B-SRSS-TB(LF)(SN); JST_SM06B-SRSS-TB(LF)(SN)
LED1: LEDCHIP-LED0805; CHIP-LED0805
R1: 91r; R0805
SW1: PCM12SMTR; SW_PCM12SMTR

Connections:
+3V3: J2.4
+5V: J1.VCC, J2.1, R1.1, SW1.3
GND: J1.GND, J1.P$5 (CASE), J1.P$6 (CASE), J2.6, J2.S1 (SHIELD), J2.S2 (SHIELD), SW1.1, SW1.S1 (SHIELD), SW1.S2 (SHIELD), SW1.S3 (SHIELD), SW1.S4 (SHIELD)
unnamed: LED1.A, R1.2
OGX_DISABLE: J2.5, LED1.C, SW1.2
USB_DN: J1.D-, J2.2
USB_DP: J1.D+, J2.3

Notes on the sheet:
Signal HIGH disables OGX360

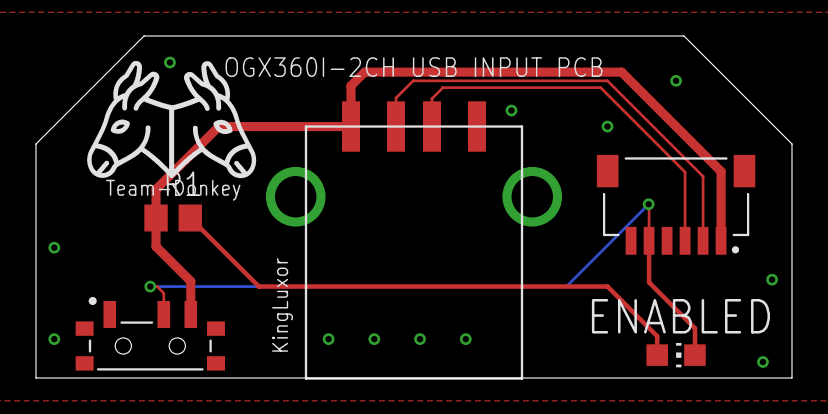
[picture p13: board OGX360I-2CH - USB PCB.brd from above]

Board: 2 copper layers, 42.0 x 19.0 mm, 5 parts (0 on the bottom side), 6 nets.

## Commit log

2020-10-04 Initial commit (see extended)
    The files contained within this repo should be considered to be in the prototype stage of verification until you have verified them yourself or I have made a commit stating otherwise.
    [OGX360I-2CH - USB PCB.brd, OGX360I-2CH - USB PCB.sch, OGX360I-2CH.brd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]
2020-10-06 Add images/readme for main pcb
2020-10-06 FIx readme location for main pcb
2020-10-06 Fix main PCB BOM table
2020-10-09 Add README.md to USB PCB
2020-10-18 Add .stl files for 3d printed case
    [OGX360I-top.stl, OGX36I-bottom.stl]

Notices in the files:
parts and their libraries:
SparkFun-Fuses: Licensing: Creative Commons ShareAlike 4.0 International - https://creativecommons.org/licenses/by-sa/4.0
